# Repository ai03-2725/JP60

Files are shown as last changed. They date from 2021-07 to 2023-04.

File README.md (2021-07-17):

# JP60  
GH60互換疑似JISキーボードPCB  
GH60-compatible JIS-like hotswap keyboard PCB

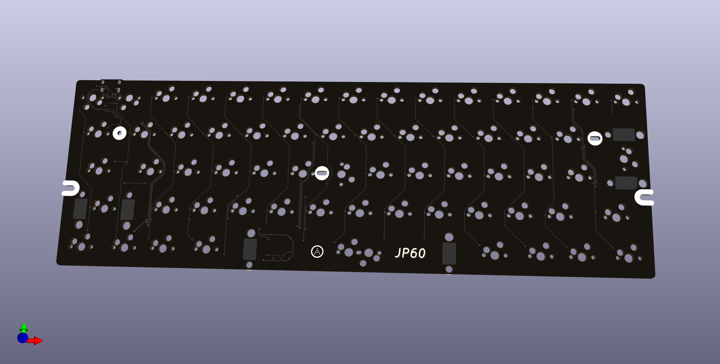
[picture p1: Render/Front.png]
Render
  

Features  
- MITライセンスのもとでソース公開 / Open-source under the MIT license  
- Kailh製ソケットで全キーホットスワップ可能、はんだ付け無しで組み立て可能 / Fully hotswap  
- GH60対応の60％ケースで使用可能 / Compatible with GH60 standard cases  
- 一般的なキーサイズのみの日本語入力配列なので、GMKやePBTなどの標準キーキャップセットを使用可能 / Features a JIS-like key layout using standard keycap sizes   

[配列データ / Layout data](http://www.keyboard-layout-editor.com/#/gists/8acf5e6dbc672aa6a96d8ddba1245e7f)  
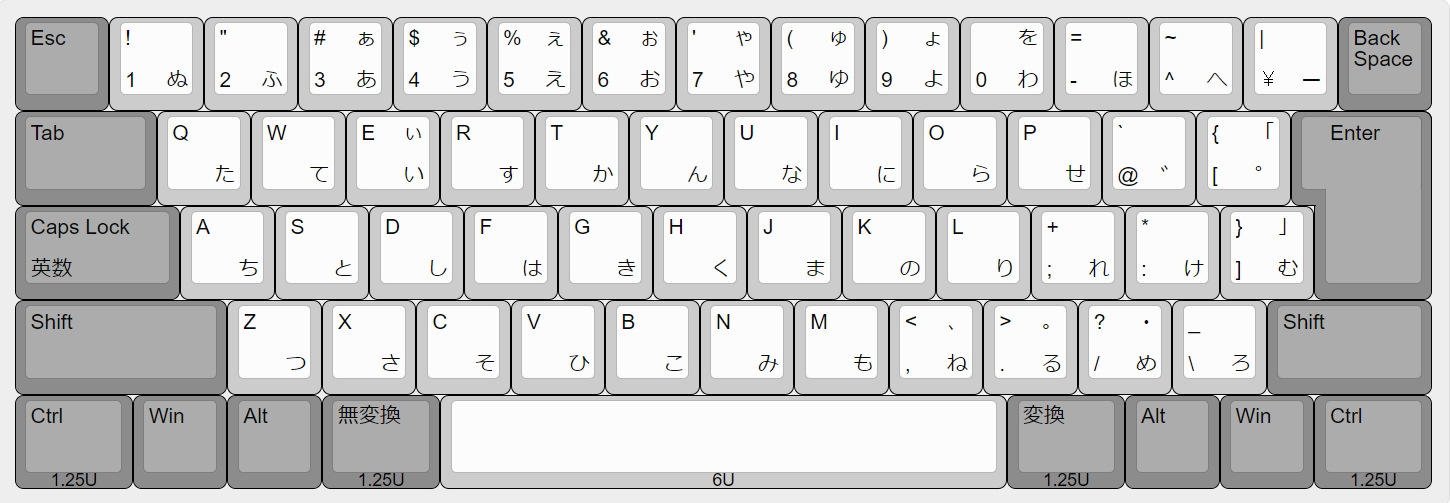
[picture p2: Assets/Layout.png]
Layout Image


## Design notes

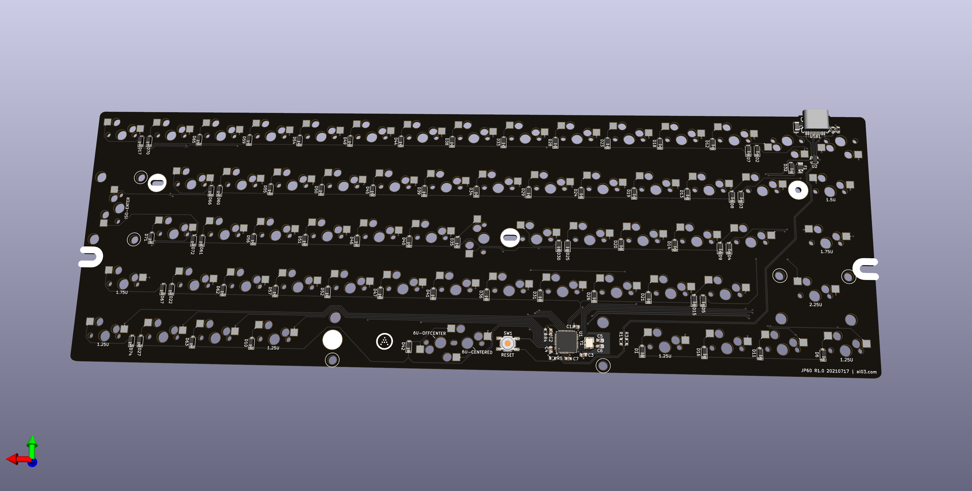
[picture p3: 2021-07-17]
Render/Rear.png

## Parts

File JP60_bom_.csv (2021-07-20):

Component | Description | Part | References | Value | Footprint | Quantity Per PCB | Datasheet
1 | Unpolarized capacitor, small symbol | C_Small | C1 C2 C3 | 0.1uF | C_0603_1608Metric | 3 | ~
2 | Unpolarized capacitor, small symbol | C_Small | C4 | 10uF | C_0603_1608Metric | 1 | ~
3 | Unpolarized capacitor, small symbol | C_Small | C7 | 1uF | C_0603_1608Metric | 1 | ~
4 | Unpolarized capacitor, small symbol | C_Small | C5 C6 | 22pF | C_0603_1608Metric | 2 | ~
5 | Bidirectional transient-voltage-suppression diode | D_TVS | D32 | SMF6.0CA | D_SOD-123 | 1 | ~
6 | Diode, small symbol | D_Small | D1 D2 D3 D4 D5 D6 D7 D8 D9 D10 D11 D12 D13 D14 D15 D16 D17 D18 D19 D20 D21 D22 D23 D24 D25 D26 D27 D28 D29 D30 D31 D33 D34 D35 D36 D38 D39 D40 D41 D42 D44 D45 D46 D47 D49 D50 D51 D52 D54 D55 D56 D57 D59 D60 D61 D62 D63 D65 D66 D67 D70 D71 D72 D74 | SOD-123 | D_SOD-123 | 64 | ~
7 | Resettable fuse, polymeric positive temperature coefficient, small symbol | Polyfuse_Small | F1 | Polyfuse_Small | Fuse_1206_3216Metric | 1 | ~
8 | MX Hotswap Socket | Kailh-Hotswap-Socket | K_CAPS1 | MX-LED | MXOnly-1.75U-Hotswap | 1
9 | MX Hotswap Socket | Kailh-Hotswap-Socket | K_#0_1 K_#1 K_#2 K_#3 K_#4 K_#5 K_#6 K_#7 K_#8 K_#9 K_'1 K_,1 K_-1 K_.1 K_/1 K_;1 K_=1 K_A1 K_B1 K_C1 K_D1 K_E1 K_ESC1 K_F1 K_G1 K_H1 K_I1 K_J1 K_K1 K_L1 K_LALT1 K_LGUI1 K_M1 K_N1 K_O1 K_P1 K_Q1 K_R1 K_RALT1 K_RGUI1 K_S1 K_SBSPC1 K_SBSPC2 K_SPC2 K_SRSFT1 K_T1 K_U1 K_V1 K_W1 K_X1 K_Y1 K_Z1 K_[1 K_\1 K_]1 | MX-NoLED | MXOnly-1U-Hotswap | 55
10 | MX Hotswap Socket | Kailh-Hotswap-Socket | K_ENTER1 | MX-NoLED | MXOnly-ISO-ROTATED-Hotswap | 1
11 | MX Hotswap Socket | Kailh-Hotswap-Socket | K_LCTRL1 K_NFER1 K_RCTRL1 K_XFER1 | MX-NoLED | MXOnly-1.25U-Hotswap | 4
12 | MX Hotswap Socket | Kailh-Hotswap-Socket | K_LSFT1 | MX-NoLED | MXOnly-2.25U-Hotswap | 1
13 | MX Hotswap Socket | Kailh-Hotswap-Socket | K_SPC1 | MX-NoLED | MXOnly-6U-Centered-Hotswap-ReversedStabilizers | 1
14 | MX Hotswap Socket | Kailh-Hotswap-Socket | K_SRSFT2 | MX-NoLED | MXOnly-1.75U-Hotswap | 1
15 | MX Hotswap Socket | Kailh-Hotswap-Socket | K_TAB1 | MX-NoLED | MXOnly-1.5U-Hotswap | 1
16 | Inductor with ferrite core, small symbol | L_Core_Ferrite_Small | L1 | 60R@100MHz | L_1206_3216Metric | 1 | ~
17 | Resistor, small symbol | R_Small | R5 | 10k | R_0603_1608Metric | 1 | ~
18 | Resistor, small symbol | R_Small | R4 | 1k | R_0603_1608Metric | 1 | ~
19 | Resistor, small symbol | R_Small | R1 R3 | 22 | R_0603_1608Metric | 2 | ~
20 | Resistor, small symbol | R_Small | R2 R6 | 5.1k | R_0603_1608Metric | 2 | ~
21 | Push button switch, generic, two pins | SW_Push | SW1 | SW_Push | SW_SPST_TL3342 | 1 | ~
22 | 16MHz, 16kB Flash, 1.25kB SRAM, 512B EEPROM, USB 2.0, QFN-44 | ATmega32U4-MU | U1 | ATmega32U4-MU | QFN-44-1EP_7x7mm_P0.5mm_EP5.2x5.2mm | 1 | http://ww1.microchip.com/downloads/en/DeviceDoc/Atmel-7766-8-bit-AVR-ATmega16U4-32U4_Datasheet.pdf
23 | ESD Protection IC | PRTR5V0U2X | U2 | PRTR5V0U2X | SOT143B | 1
24 | USB Type-C Connector | HRO-TYPE-C-31-M-12 | USB1 | HRO-TYPE-C-31-M-12 | HRO-TYPE-C-31-M-12-Assembly | 1
25 | Four pin crystal, GND on pins 2 and 4, small symbol | Crystal_GND24_Small | Y1 | 16MHz | Crystal_SMD_3225-4Pin_3.2x2.5mm | 1 | ~
Component Groups: | 25
Component Count: | 150
Fitted Components: | 150
Number of PCBs: | 1
Total components: | 150
Schematic Version:
Schematic Date:
BoM Date: | 7/20/2021 11:11:11 PM
Schematic Source: | C:\Users\ai03\Documents\GitHub\JIS60\JP60.sch
KiCad Version: | Eeschema (5.1.4)-1

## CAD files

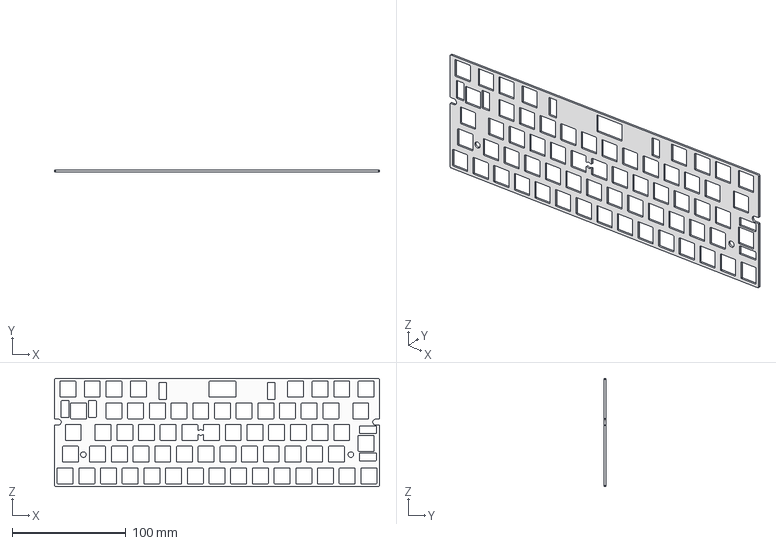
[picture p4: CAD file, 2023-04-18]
Plate/JP60-Plate-20230418.step
285.4 x 1.50 x 94.9 mm

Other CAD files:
Plate/JP60-Plate-20230418.dxf

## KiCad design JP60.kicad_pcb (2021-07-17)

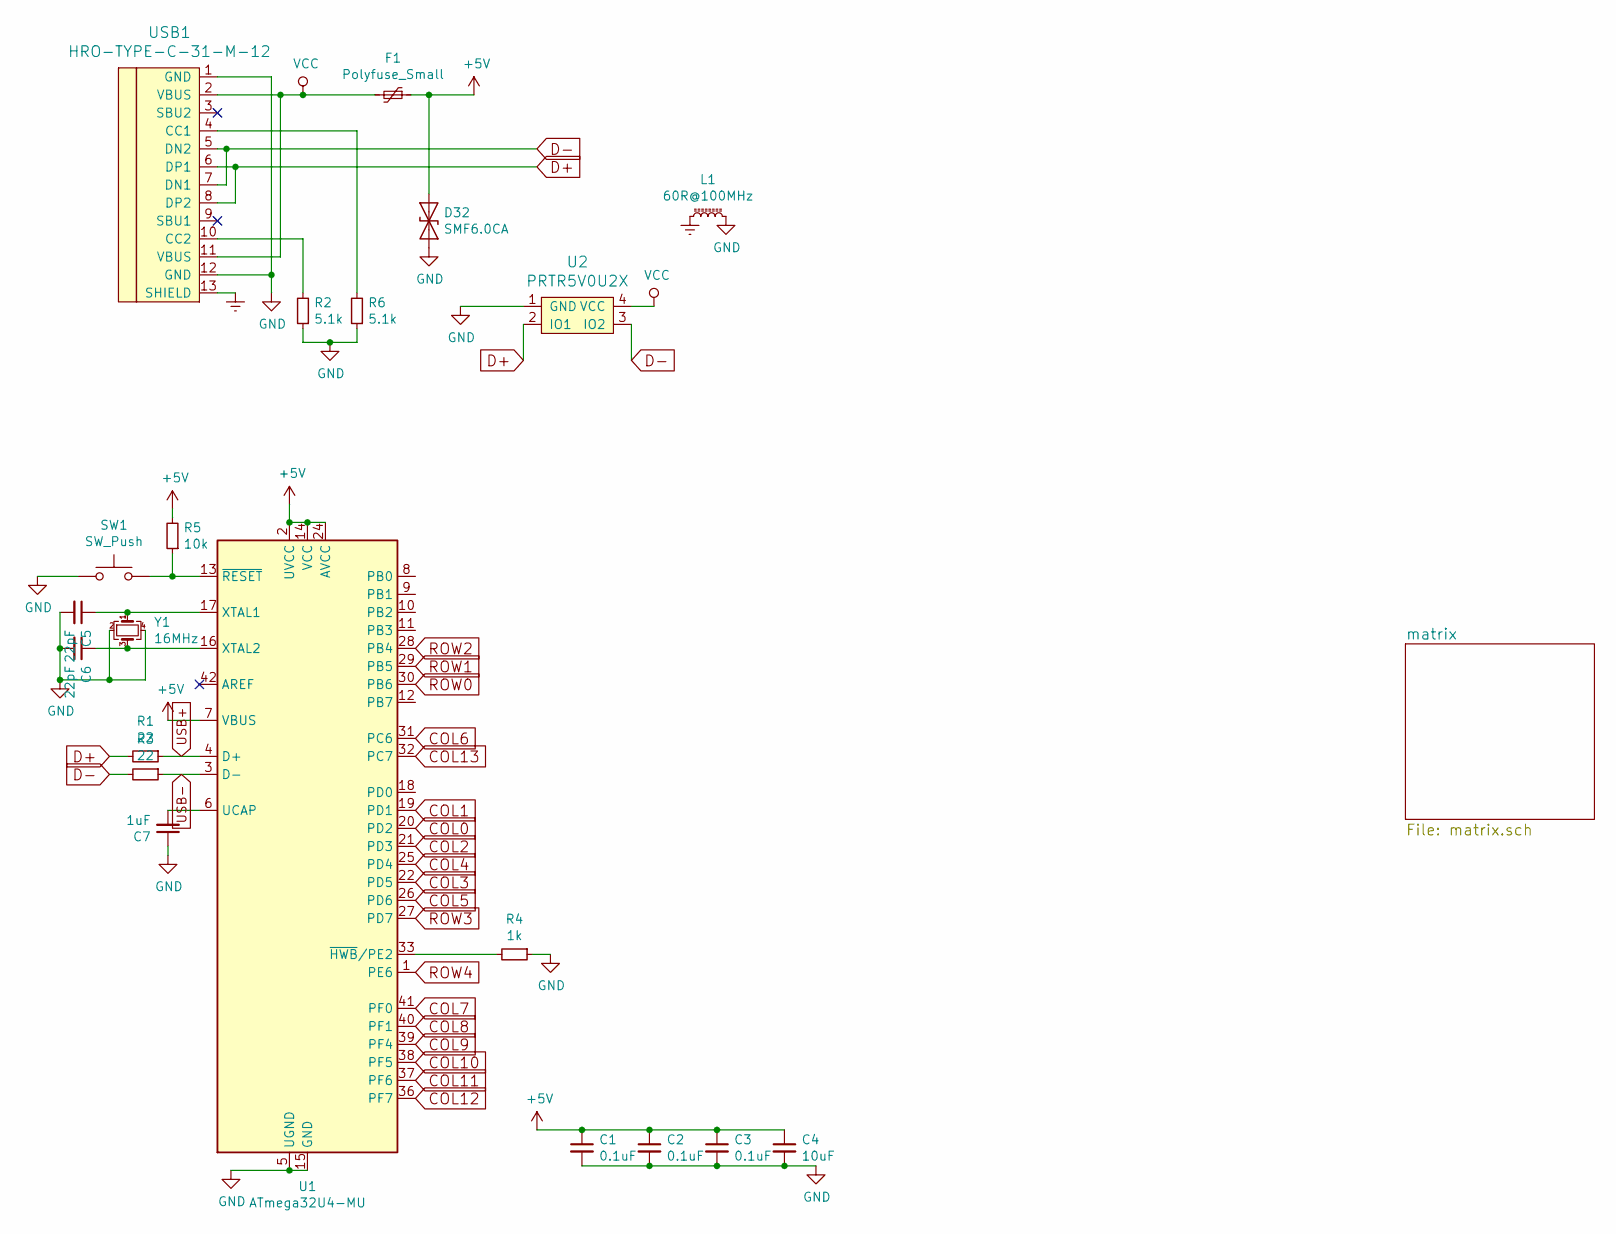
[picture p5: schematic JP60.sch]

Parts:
C1, C2, C3: 0.1uF; C_0603_1608Metric
C4: 10uF; C_0603_1608Metric
C5, C6: 22pF; C_0603_1608Metric
C7: 1uF; C_0603_1608Metric
D32: SMF6.0CA; D_SOD-123
F1: Polyfuse_Small; Fuse_1206_3216Metric
L1: 60R@100MHz; L_1206_3216Metric
R1, R3: 22; R_0603_1608Metric
R2, R6: 5.1k; R_0603_1608Metric
R4: 1k; R_0603_1608Metric
R5: 10k; R_0603_1608Metric
SW1: SW_Push; SW_SPST_TL3342
U1: ATmega32U4-MU; QFN-44-1EP_7x7mm_P0.5mm_EP5.2x5.2mm
U2: PRTR5V0U2X; SOT143B
USB1: HRO-TYPE-C-31-M-12; HRO-TYPE-C-31-M-12-Assembly
Y1: 16MHz; Crystal_SMD_3225-4Pin_3.2x2.5mm

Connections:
+5V: C1.1, C2.1, C3.1, C4.1, D32.2 (A2), F1.1, R5.2, U1.2 (UVCC), U1.7 (VBUS), U1.14 (VCC), U1.24 (AVCC), U1.34 (VCC), U1.44 (AVCC)
COL0: U1.20 (PD2); also elsewhere on the board
COL1: U1.19 (PD1); also elsewhere on the board
COL2: U1.21 (PD3); also elsewhere on the board
COL3: U1.22 (PD5); also elsewhere on the board
COL4: U1.25 (PD4); also elsewhere on the board
COL5: U1.26 (PD6); also elsewhere on the board
COL6: U1.31 (PC6); also elsewhere on the board
COL7: U1.41 (PF0); also elsewhere on the board
COL8: U1.40 (PF1); also elsewhere on the board
COL9: U1.39 (PF4); also elsewhere on the board
COL10: U1.38 (PF5); also elsewhere on the board
COL11: U1.37 (PF6); also elsewhere on the board
COL12: U1.36 (PF7); also elsewhere on the board
COL13: U1.32 (PC7); also elsewhere on the board
D+: R1.2, U2.2 (IO1), USB1.6 (DP1), USB1.8 (DP2)
D-: R3.2, U2.3 (IO2), USB1.5 (DN2), USB1.7 (DN1)
Earth: L1.1, USB1.13 (SHIELD)
GND: C1.2, C2.2, C3.2, C4.2, C5.2, C6.2, C7.1, D32.1 (A1), L1.2, R2.1, R4.1, R6.1, SW1.1, U1.5 (UGND), U1.15 (GND), U1.23 (GND), U1.35 (GND), U1.43 (GND), U1.45 (GND), U2.1 (GND), USB1.1 (GND), USB1.12 (GND), Y1.2, Y1.4
unnamed: C5.1, U1.17 (XTAL1), Y1.1
unnamed: C6.1, U1.16 (XTAL2), Y1.3
unnamed: C7.2, U1.6 (UCAP)
unnamed: R2.2, USB1.10 (CC2)
unnamed: R4.2, U1.33 (~HWB~/PE2)
unnamed: R5.1, SW1.2, U1.13 (~RESET)
unnamed: R6.2, USB1.4 (CC1)
ROW0: U1.30 (PB6); also elsewhere on the board
ROW1: U1.29 (PB5); also elsewhere on the board
ROW2: U1.28 (PB4); also elsewhere on the board
ROW3: U1.27 (PD7); also elsewhere on the board
ROW4: U1.1 (PE6); also elsewhere on the board
USB+: R1.1, U1.4 (D+)
USB-: R3.1, U1.3 (D-)
VCC: F1.2, U2.4 (VCC), USB1.2 (VBUS), USB1.11 (VBUS)

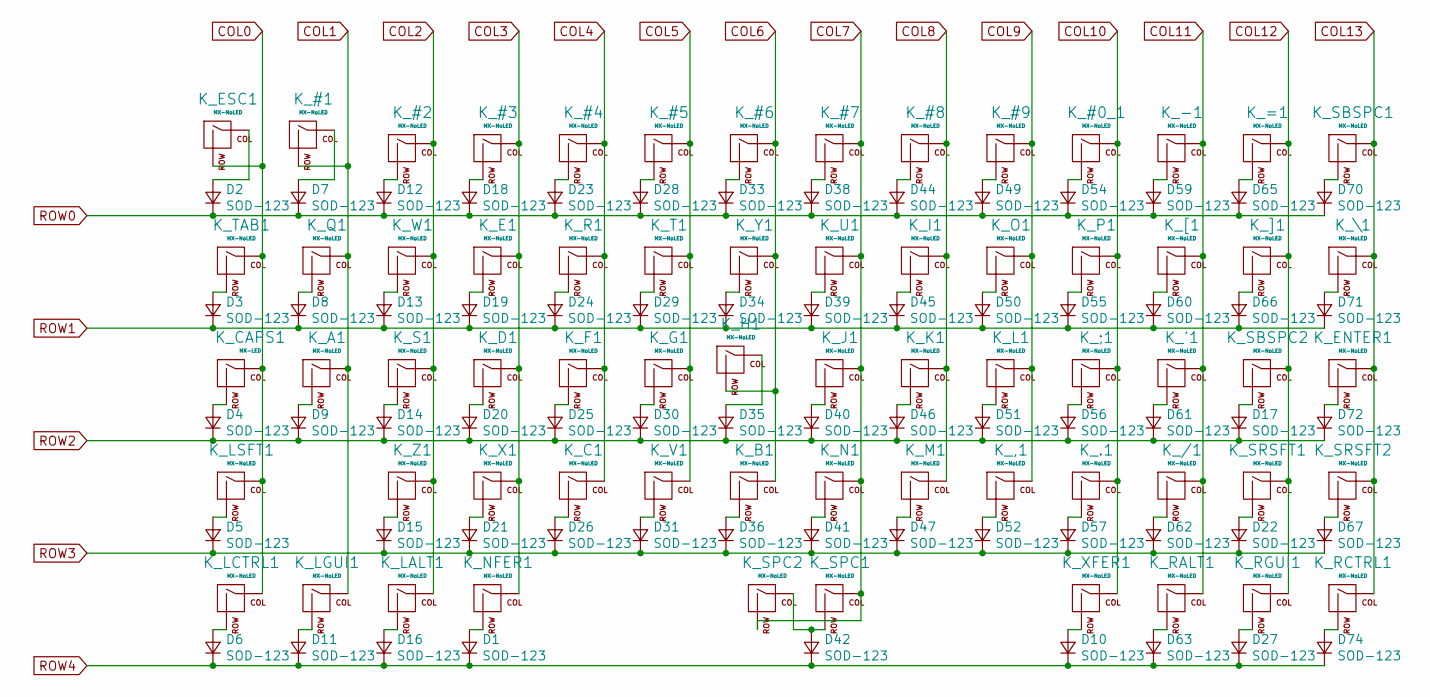
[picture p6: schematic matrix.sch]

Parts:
D1, D2, D3, D4, D5, D6, D7, D8, D9, D10, D11, D12, D13, D14, D15, D16, D17, D18, D19, D20, D21, D22, D23, D24, D25, D26, D27, D28, D29, D30, D31, D33, D34, D35, D36, D38, D39, D40, D41, D42, D44, D45, D46, D47, D49, D50, D51, D52, D54, D55, D56, D57, D59, D60, D61, D62, D63, D65, D66, D67, D70, D71, D72, D74: SOD-123; D_SOD-123
K_#0_1, K_#1, K_#2, K_#3, K_#4, K_#5, K_#6, K_#7, K_#8, K_#9: MX-NoLED; MXOnly-1U-Hotswap
K_'1: MX-NoLED; MXOnly-1U-Hotswap
K_,1: MX-NoLED; MXOnly-1U-Hotswap
K_-1: MX-NoLED; MXOnly-1U-Hotswap
K_.1: MX-NoLED; MXOnly-1U-Hotswap
K_/1: MX-NoLED; MXOnly-1U-Hotswap
K_;1: MX-NoLED; MXOnly-1U-Hotswap
K_=1: MX-NoLED; MXOnly-1U-Hotswap
K_A1: MX-NoLED; MXOnly-1U-Hotswap
K_B1: MX-NoLED; MXOnly-1U-Hotswap
K_C1: MX-NoLED; MXOnly-1U-Hotswap
K_CAPS1: MX-LED; MXOnly-1.75U-Hotswap
K_D1: MX-NoLED; MXOnly-1U-Hotswap
K_E1: MX-NoLED; MXOnly-1U-Hotswap
K_ENTER1: MX-NoLED; MXOnly-ISO-ROTATED-Hotswap
K_ESC1: MX-NoLED; MXOnly-1U-Hotswap
K_F1: MX-NoLED; MXOnly-1U-Hotswap
K_G1: MX-NoLED; MXOnly-1U-Hotswap
K_H1: MX-NoLED; MXOnly-1U-Hotswap
K_I1: MX-NoLED; MXOnly-1U-Hotswap
K_J1: MX-NoLED; MXOnly-1U-Hotswap
K_K1: MX-NoLED; MXOnly-1U-Hotswap
K_L1: MX-NoLED; MXOnly-1U-Hotswap
K_LALT1: MX-NoLED; MXOnly-1U-Hotswap
K_LCTRL1: MX-NoLED; MXOnly-1.25U-Hotswap
K_LGUI1: MX-NoLED; MXOnly-1U-Hotswap
K_LSFT1: MX-NoLED; MXOnly-2.25U-Hotswap
K_M1: MX-NoLED; MXOnly-1U-Hotswap
K_N1: MX-NoLED; MXOnly-1U-Hotswap
K_NFER1: MX-NoLED; MXOnly-1.25U-Hotswap
K_O1: MX-NoLED; MXOnly-1U-Hotswap
K_P1: MX-NoLED; MXOnly-1U-Hotswap
K_Q1: MX-NoLED; MXOnly-1U-Hotswap
K_R1: MX-NoLED; MXOnly-1U-Hotswap
K_RALT1: MX-NoLED; MXOnly-1U-Hotswap
K_RCTRL1: MX-NoLED; MXOnly-1.25U-Hotswap
K_RGUI1: MX-NoLED; MXOnly-1U-Hotswap
K_S1: MX-NoLED; MXOnly-1U-Hotswap
K_SBSPC1, K_SBSPC2: MX-NoLED; MXOnly-1U-Hotswap
K_SPC1: MX-NoLED; MXOnly-6U-Centered-Hotswap-ReversedStabilizers
K_SPC2: MX-NoLED; MXOnly-1U-Hotswap
K_SRSFT1: MX-NoLED; MXOnly-1U-Hotswap
K_SRSFT2: MX-NoLED; MXOnly-1.75U-Hotswap
K_T1: MX-NoLED; MXOnly-1U-Hotswap
K_TAB1: MX-NoLED; MXOnly-1.5U-Hotswap
K_U1: MX-NoLED; MXOnly-1U-Hotswap
K_V1: MX-NoLED; MXOnly-1U-Hotswap
K_W1: MX-NoLED; MXOnly-1U-Hotswap
K_X1: MX-NoLED; MXOnly-1U-Hotswap
K_XFER1: MX-NoLED; MXOnly-1.25U-Hotswap
K_Y1: MX-NoLED; MXOnly-1U-Hotswap
K_Z1: MX-NoLED; MXOnly-1U-Hotswap
K_[1: MX-NoLED; MXOnly-1U-Hotswap
K_\1: MX-NoLED; MXOnly-1U-Hotswap
K_]1: MX-NoLED; MXOnly-1U-Hotswap

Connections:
COL0: K_CAPS1.1 (COL), K_ESC1.2 (ROW), K_LCTRL1.1 (COL), K_LSFT1.1 (COL), K_TAB1.1 (COL); also elsewhere on the board
COL1: K_#1.2 (ROW), K_A1.1 (COL), K_LGUI1.1 (COL), K_Q1.1 (COL); also elsewhere on the board
COL2: K_#2.1 (COL), K_LALT1.1 (COL), K_S1.1 (COL), K_W1.1 (COL), K_Z1.1 (COL); also elsewhere on the board
COL3: K_#3.1 (COL), K_D1.1 (COL), K_E1.1 (COL), K_NFER1.1 (COL), K_X1.1 (COL); also elsewhere on the board
COL4: K_#4.1 (COL), K_C1.1 (COL), K_F1.1 (COL), K_R1.1 (COL); also elsewhere on the board
COL5: K_#5.1 (COL), K_G1.1 (COL), K_T1.1 (COL), K_V1.1 (COL); also elsewhere on the board
COL6: K_#6.1 (COL), K_B1.1 (COL), K_H1.2 (ROW), K_Y1.1 (COL); also elsewhere on the board
COL7: K_#7.1 (COL), K_J1.1 (COL), K_N1.1 (COL), K_SPC1.1 (COL), K_SPC2.2 (ROW), K_U1.1 (COL); also elsewhere on the board
COL8: K_#8.1 (COL), K_I1.1 (COL), K_K1.1 (COL), K_M1.1 (COL); also elsewhere on the board
COL9: K_#9.1 (COL), K_,1.1 (COL), K_L1.1 (COL), K_O1.1 (COL); also elsewhere on the board
COL10: K_#0_1.1 (COL), K_.1.1 (COL), K_;1.1 (COL), K_P1.1 (COL), K_XFER1.1 (COL); also elsewhere on the board
COL11: K_'1.1 (COL), K_-1.1 (COL), K_/1.1 (COL), K_RALT1.1 (COL), K_[1.1 (COL); also elsewhere on the board
COL12: K_=1.1 (COL), K_RGUI1.1 (COL), K_SBSPC2.1 (COL), K_SRSFT1.1 (COL), K_]1.1 (COL); also elsewhere on the board
COL13: K_ENTER1.1 (COL), K_RCTRL1.1 (COL), K_SBSPC1.1 (COL), K_SRSFT2.1 (COL), K_\1.1 (COL); also elsewhere on the board
unnamed: D1.2 (A), K_NFER1.2 (ROW)
unnamed: D2.2 (A), K_ESC1.1 (COL)
unnamed: D3.2 (A), K_TAB1.2 (ROW)
unnamed: D4.2 (A), K_CAPS1.2 (ROW)
unnamed: D5.2 (A), K_LSFT1.2 (ROW)
unnamed: D6.2 (A), K_LCTRL1.2 (ROW)
unnamed: D7.2 (A), K_#1.1 (COL)
unnamed: D8.2 (A), K_Q1.2 (ROW)
unnamed: D9.2 (A), K_A1.2 (ROW)
unnamed: D10.2 (A), K_XFER1.2 (ROW)
unnamed: D11.2 (A), K_LGUI1.2 (ROW)
unnamed: D12.2 (A), K_#2.2 (ROW)
unnamed: D13.2 (A), K_W1.2 (ROW)
unnamed: D14.2 (A), K_S1.2 (ROW)
unnamed: D15.2 (A), K_Z1.2 (ROW)
unnamed: D16.2 (A), K_LALT1.2 (ROW)
unnamed: D17.2 (A), K_SBSPC2.2 (ROW)
unnamed: D18.2 (A), K_#3.2 (ROW)
unnamed: D19.2 (A), K_E1.2 (ROW)
unnamed: D20.2 (A), K_D1.2 (ROW)
unnamed: D21.2 (A), K_X1.2 (ROW)
unnamed: D22.2 (A), K_SRSFT1.2 (ROW)
unnamed: D23.2 (A), K_#4.2 (ROW)
unnamed: D24.2 (A), K_R1.2 (ROW)
unnamed: D25.2 (A), K_F1.2 (ROW)
unnamed: D26.2 (A), K_C1.2 (ROW)
unnamed: D27.2 (A), K_RGUI1.2 (ROW)
unnamed: D28.2 (A), K_#5.2 (ROW)
unnamed: D29.2 (A), K_T1.2 (ROW)
unnamed: D30.2 (A), K_G1.2 (ROW)
unnamed: D31.2 (A), K_V1.2 (ROW)
unnamed: D33.2 (A), K_#6.2 (ROW)
unnamed: D34.2 (A), K_Y1.2 (ROW)
unnamed: D35.2 (A), K_H1.1 (COL)
unnamed: D36.2 (A), K_B1.2 (ROW)
unnamed: D38.2 (A), K_#7.2 (ROW)
unnamed: D39.2 (A), K_U1.2 (ROW)
unnamed: D40.2 (A), K_J1.2 (ROW)
unnamed: D41.2 (A), K_N1.2 (ROW)
unnamed: D42.2 (A), K_SPC1.2 (ROW), K_SPC2.1 (COL)
unnamed: D44.2 (A), K_#8.2 (ROW)
unnamed: D45.2 (A), K_I1.2 (ROW)
unnamed: D46.2 (A), K_K1.2 (ROW)
unnamed: D47.2 (A), K_M1.2 (ROW)
unnamed: D49.2 (A), K_#9.2 (ROW)
unnamed: D50.2 (A), K_O1.2 (ROW)
unnamed: D51.2 (A), K_L1.2 (ROW)
unnamed: D52.2 (A), K_,1.2 (ROW)
unnamed: D54.2 (A), K_#0_1.2 (ROW)
unnamed: D55.2 (A), K_P1.2 (ROW)
unnamed: D56.2 (A), K_;1.2 (ROW)
unnamed: D57.2 (A), K_.1.2 (ROW)
unnamed: D59.2 (A), K_-1.2 (ROW)
unnamed: D60.2 (A), K_[1.2 (ROW)
unnamed: D61.2 (A), K_'1.2 (ROW)
unnamed: D62.2 (A), K_/1.2 (ROW)
unnamed: D63.2 (A), K_RALT1.2 (ROW)
unnamed: D65.2 (A), K_=1.2 (ROW)
unnamed: D66.2 (A), K_]1.2 (ROW)
unnamed: D67.2 (A), K_SRSFT2.2 (ROW)
unnamed: D70.2 (A), K_SBSPC1.2 (ROW)
unnamed: D71.2 (A), K_\1.2 (ROW)
unnamed: D72.2 (A), K_ENTER1.2 (ROW)
unnamed: D74.2 (A), K_RCTRL1.2 (ROW)
ROW0: D2.1 (K), D7.1 (K), D12.1 (K), D18.1 (K), D23.1 (K), D28.1 (K), D33.1 (K), D38.1 (K), D44.1 (K), D49.1 (K), D54.1 (K), D59.1 (K), D65.1 (K), D70.1 (K); also elsewhere on the board
ROW1: D3.1 (K), D8.1 (K), D13.1 (K), D19.1 (K), D24.1 (K), D29.1 (K), D34.1 (K), D39.1 (K), D45.1 (K), D50.1 (K), D55.1 (K), D60.1 (K), D66.1 (K), D71.1 (K); also elsewhere on the board
ROW2: D4.1 (K), D9.1 (K), D14.1 (K), D17.1 (K), D20.1 (K), D25.1 (K), D30.1 (K), D35.1 (K), D40.1 (K), D46.1 (K), D51.1 (K), D56.1 (K), D61.1 (K), D72.1 (K); also elsewhere on the board
ROW3: D5.1 (K), D15.1 (K), D21.1 (K), D22.1 (K), D26.1 (K), D31.1 (K), D36.1 (K), D41.1 (K), D47.1 (K), D52.1 (K), D57.1 (K), D62.1 (K), D67.1 (K); also elsewhere on the board
ROW4: D1.1 (K), D6.1 (K), D10.1 (K), D11.1 (K), D16.1 (K), D27.1 (K), D42.1 (K), D63.1 (K), D74.1 (K); also elsewhere on the board

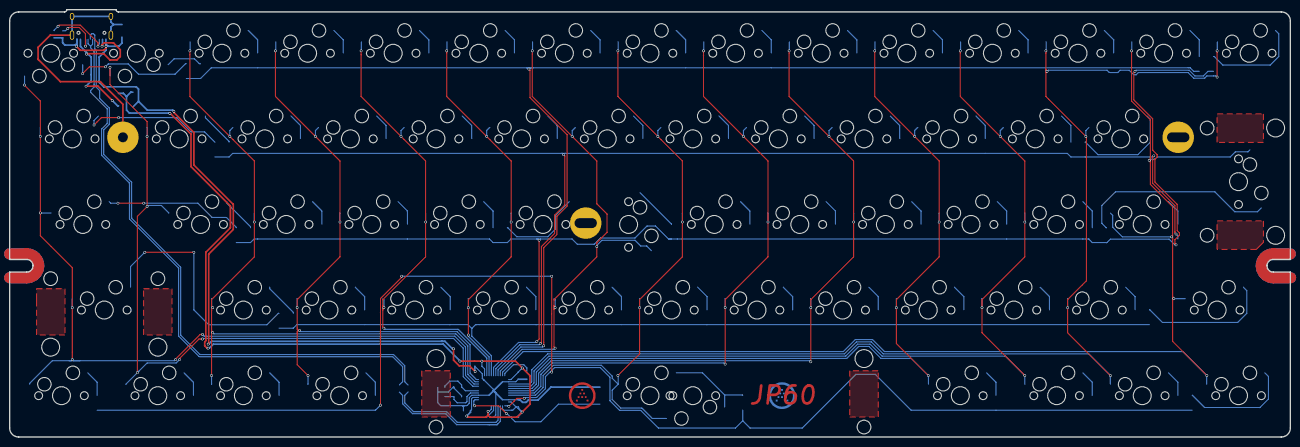
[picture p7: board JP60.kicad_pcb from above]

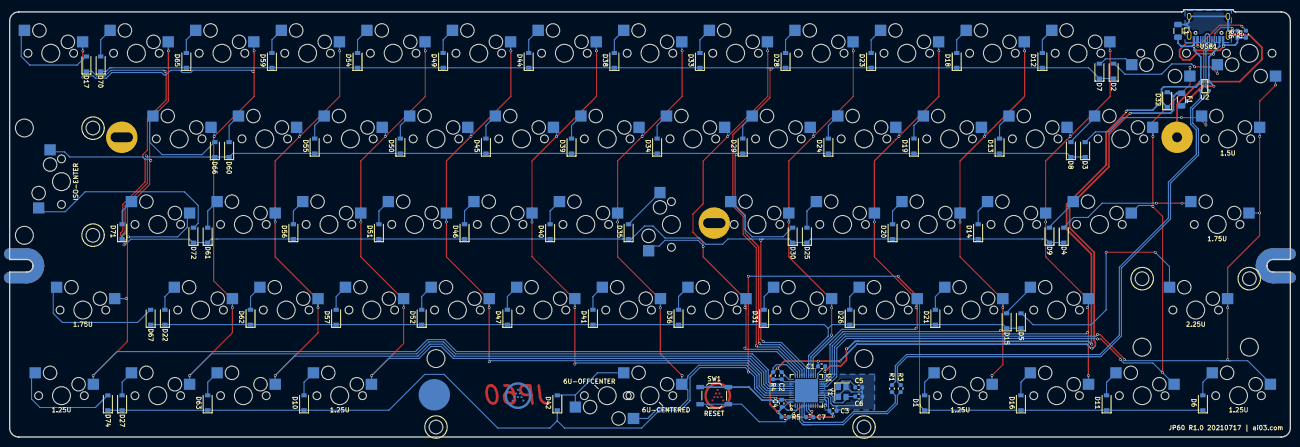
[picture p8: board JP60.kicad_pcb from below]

Board: 2 copper layers, 285.0 x 95.1 mm, 150 parts (85 on the bottom side), 98 nets.

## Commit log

2021-07-17 Transition to git
    [JIS60.kicad_pcb, JIS60.sch, JIS60_bom_.csv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]
2021-07-17 Update submod
    [JIS60.kicad_pcb, JIS60.sch, matrix.sch]
2021-07-17 Finalize data
    [JIS60.kicad_pcb, matrix.sch]
2021-07-17 Add renders
    [JIS60.kicad_pcb]
2021-07-17 Rename project files
    [JP60-B_Cu.gbl, JP60-B_Mask.gbs, JP60-B_Paste.gbp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]
2021-07-17 Add position and gerber files
    [JP60-bottom-pos.csv, JP60-top-pos.csv]
2021-07-17 Add plate files
    [JP60-Plate.dxf, JP60-Plate.step]
2021-07-20 Update production files
    [JLCSMT_Sample_BOM1.xlsx, JP60_bom_.csv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]
2021-07-23 Fix mcu rotation in JLC prod file
    [JLCSMT_Sample_CPL1.xlsx]
2021-08-07 Fix plate data
    [JP60-Plate.dxf]
2021-08-07 Update plate 3D model
    [JP60-Plate.step]
2021-08-29 Add FR4 plate data
2023-04-18 Repair plate ISO enter stabilizer cutout
    [JP60-Plate-20230418.dxf, JP60-Plate-20230418.step, JP60-Plate.dxf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]
